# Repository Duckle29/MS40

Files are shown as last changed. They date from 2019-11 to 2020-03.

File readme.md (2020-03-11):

View this project on [CADLAB.io](https://cadlab.io/project/2268). 

# MS40

[Interactive BOM](https://duckle29.github.io/MS40/ibom.html)

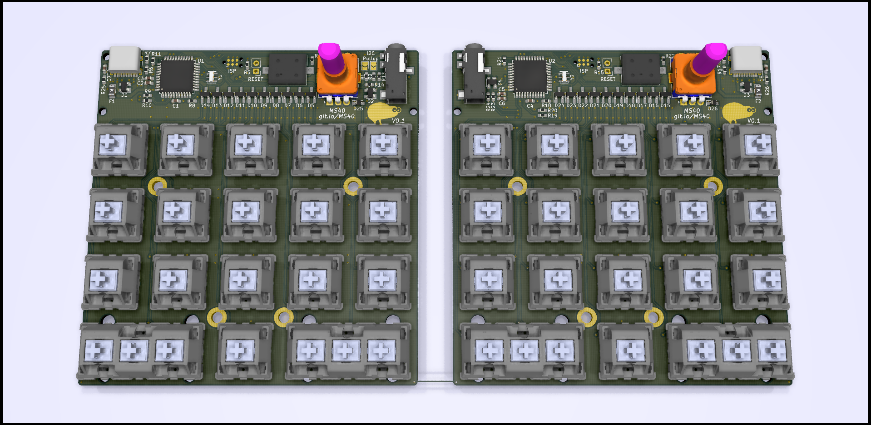
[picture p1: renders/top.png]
top render

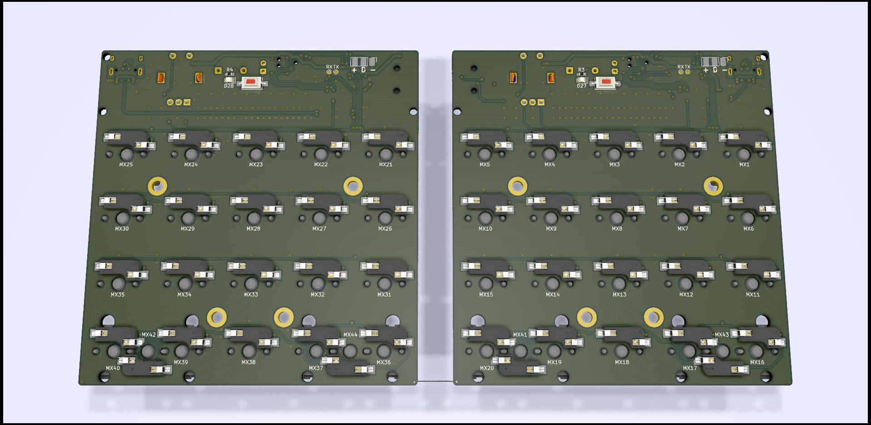
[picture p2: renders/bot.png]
bottom render


The project uses Ai03s keyswitch library.
Many thanks to Ai03 for releasing an awesome keyswitch library with an entirely open license.

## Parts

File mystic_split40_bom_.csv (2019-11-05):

Id | Designator | Package | Quantity | Designation | Supplier and ref
1 | G***,G*** | kiwi10mm | 2 | LOGO
2 | MX44,MX43,MX42,MX41 | MXOnly-2U-Hotswap | 4 | MX-NoLED
3 | J5,J2 | TestPoint_Pad_D1.0mm | 2 | TX
4 | J3,J1 | TestPoint_Pad_D1.0mm | 2 | RX
5 | F2,F1 | Fuse_1206_3216Metric_Pad1.42x1.75mm_HandSolder | 2 | ?mA fuse
6 | D3,D4,D2,D1 | SOT-143 | 4 | PRTR5V0U2X
7 | J35,J17 | PinHeader_1x03_P2.54mm_Vertical | 2 | WS2812
8 | R15,R17,R16,R21,R5,R11,R7,R6,R2,R1 | R_0603_1608Metric_Pad1.05x0.95mm_HandSolder | 10 | 5k1
9 | SW2,SW1 | RotaryEncoder_Alps_EC11E-Switch_Vertical_H20mm | 2 | EC11E
10 | SW4,SW3 | SW_SPST_CK_RS282G05A3 | 2 | Reset
11 | D26,D25 | D_SOD-323_HandSoldering | 2 | BAV70
12 | MX22,MX36,MX23,MX25,MX37,MX31,MX24,MX27,MX28,MX29,MX30,MX33,MX34,MX32,MX38,MX40,MX26,MX39,MX35,MX21,MX5,MX3,MX16,MX2,MX20,MX19,MX18,MX17,MX15,MX14,MX13,MX12,MX11,MX10,MX9,MX8,MX7,MX6,MX4,MX1 | MXOnly-1U-Hotswap | 40 | MX-NoLED
13 | U2,U1 | TQFP-44_10x10mm_P0.8mm | 2 | ATmega32U4-AU
14 | J22 | TestPoint_Pad_D1.0mm | 1 | AREF
15 | J36,J18 | SJ-43514-SMT | 2 | SJ-43514-SMT
16 | BZ3,BZ1 | Buzzer_12x9.5RM7.6 | 2 | Buzzer_magnetic
17 | R4,R24,R23,R22,R18,R3,R14,R13,R12,R8 | R_0603_1608Metric_Pad1.05x0.95mm_HandSolder | 10 | 220R
18 | D28,D27 | LED_0805_2012Metric_Pad1.15x1.40mm_HandSolder | 2 | Red LED
19 | REF**,REF**,REF**,REF**,REF**,REF** | MountingHole_2.2mm_M2_DIN965 | 6 | MountingHole_2.2mm_M2_DIN965
20 | REF**,REF**,REF**,REF**,REF**,REF**,REF**,REF** | MountingHole_3.2mm_M3_DIN965_Pad | 8 | MountingHole_3.2mm_M3_DIN965_Pad
21 | C5,C2 | C_0603_1608Metric_Pad1.05x0.95mm_HandSolder | 2 | 100nF
22 | C4,C6,C3,C1 | C_0603_1608Metric_Pad1.05x0.95mm_HandSolder | 4 | 1uF
23 | D15,D23,D21,D19,D22,D18,D20,D17,D24,D16,D6,D8,D10,D12,D14,D5,D7,D9,D11,D13 | SOT-23_Handsoldering | 20 | BAV70
24 | BZ4,BZ2 | Buzzer_Mallory_AST1109MLTRQ | 2 | Buzzer_piezo
25 | Y2,Y1 | Resonator_SMD_muRata_CSTxExxV-3Pin_3.0x1.1mm_HandSoldering | 2 | CSTNE16M0VH3L000R0
26 | R20,R19,R10,R9 | R_0603_1608Metric_Pad1.05x0.95mm_HandSolder | 4 | 22R
27 | J25,J7 | USB_C_Receptacle_HRO_TYPE-C-31-M-12 | 2 | TYPE-C-31-M-12
28 | J33,J15 | PinHeader_1x02_P2.54mm_Vertical | 2 | RESET
29 | J34,J16 | Tag-Connect_TC2030-IDC-NL_2x03_P1.27mm_Vertical | 2 | ISP
30 | JP2,JP1 | SolderJumper-2_P1.3mm_Open_TrianglePad1.0x1.5mm | 2 | I2C pullup

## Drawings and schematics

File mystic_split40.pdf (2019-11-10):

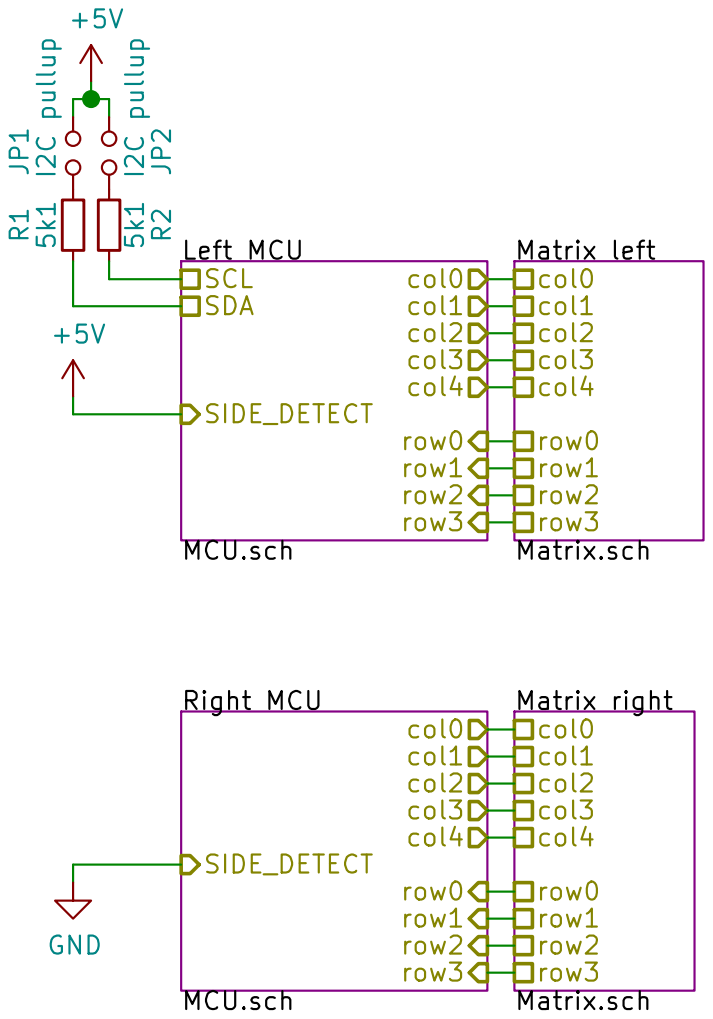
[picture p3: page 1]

row3 Right MCU MCU.sch

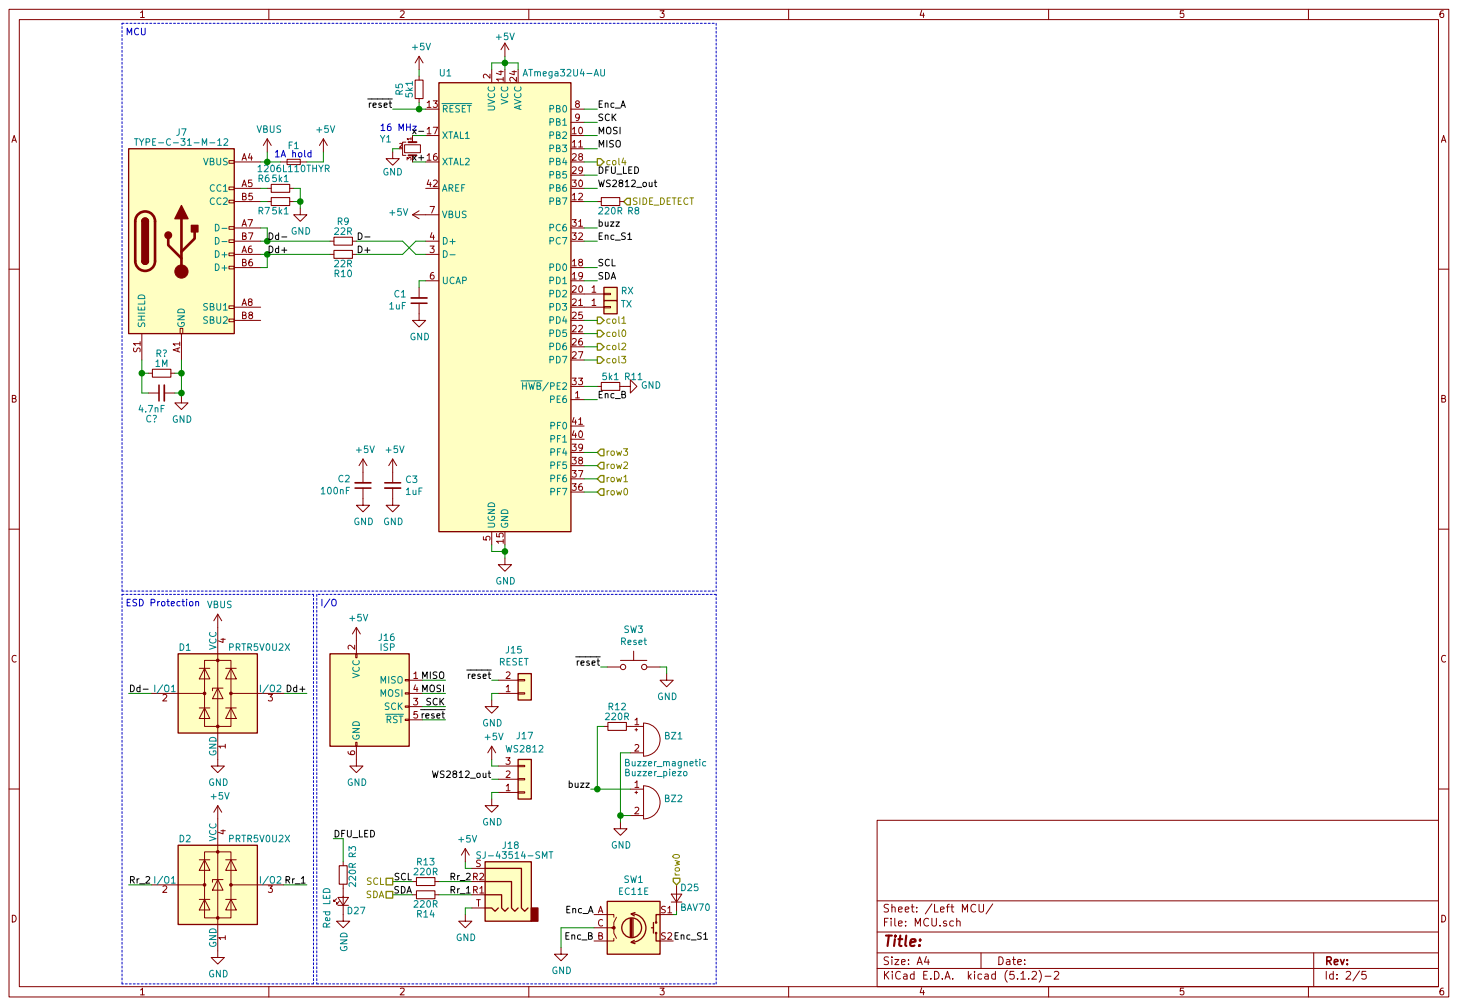
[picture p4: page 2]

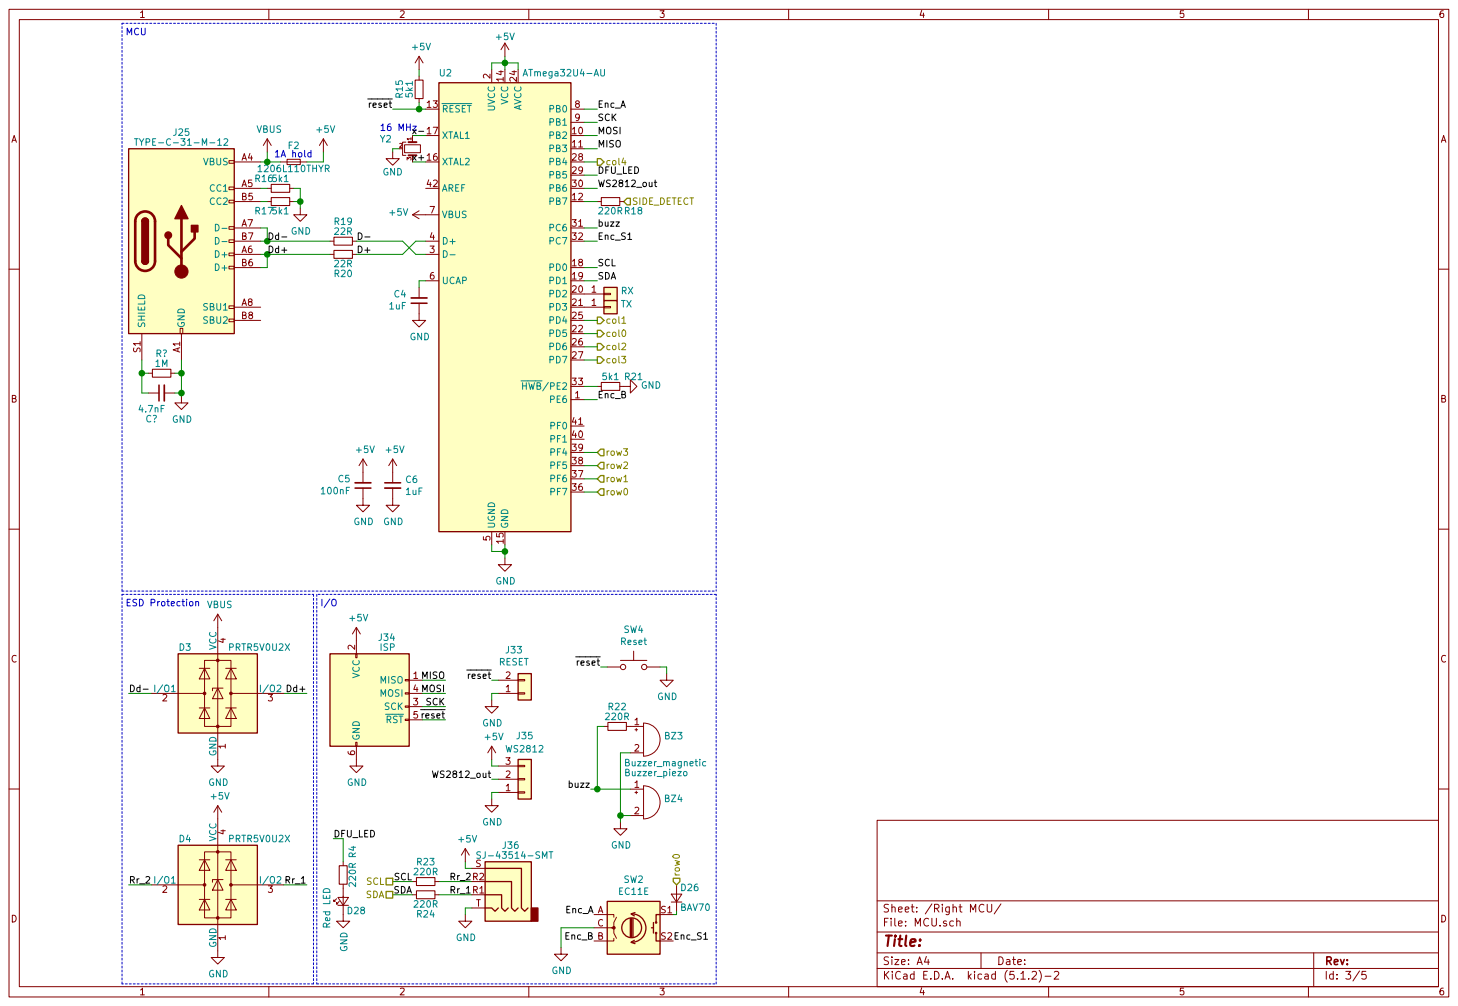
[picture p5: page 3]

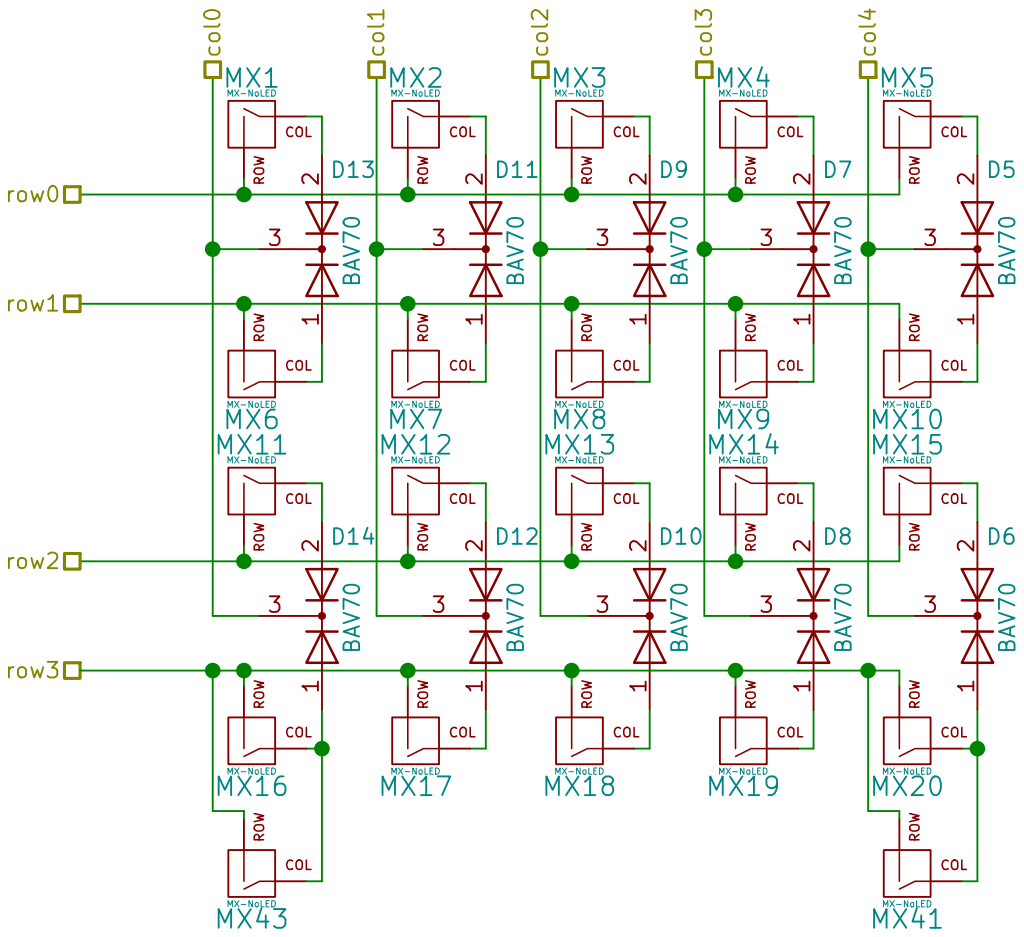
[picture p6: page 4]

Id: 4/5 Title: File: Matrix.sch Sheet: /Matrix left/

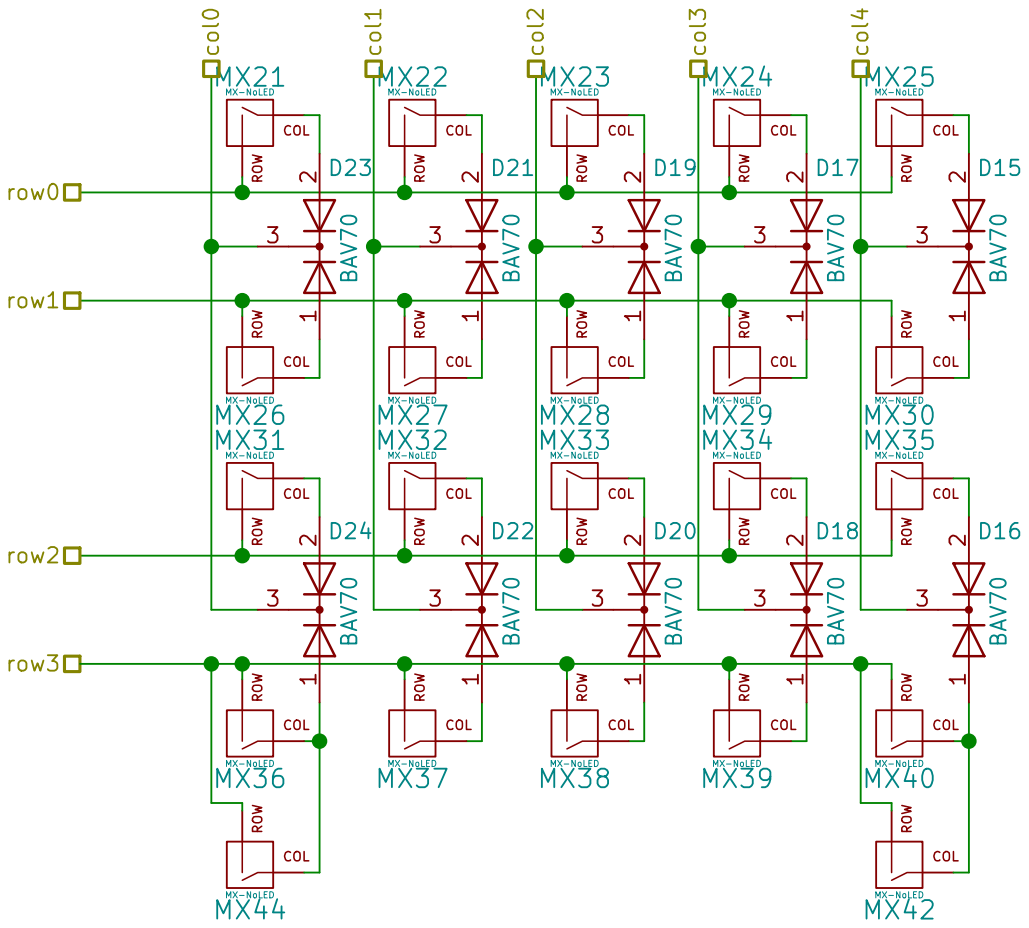
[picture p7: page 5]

Id: 5/5 Title: File: Matrix.sch Sheet: /Matrix right/

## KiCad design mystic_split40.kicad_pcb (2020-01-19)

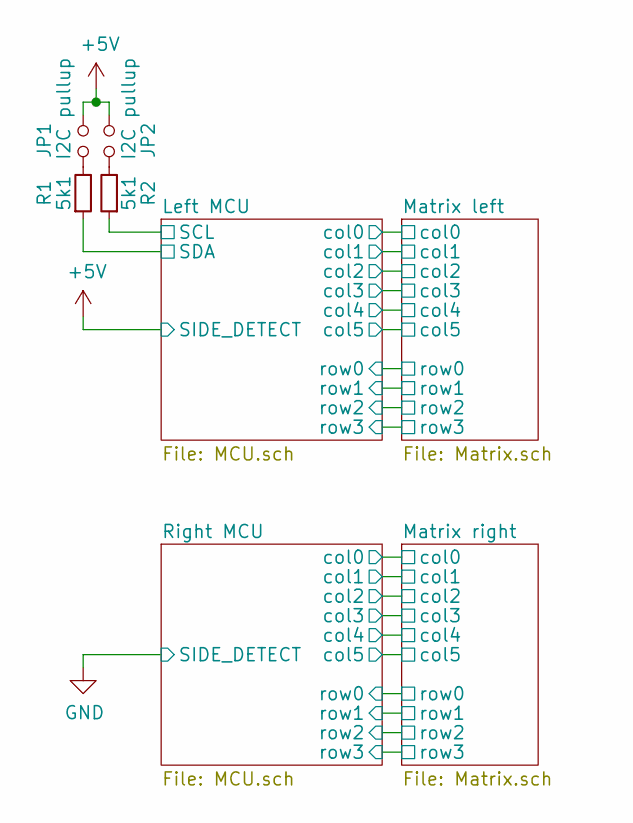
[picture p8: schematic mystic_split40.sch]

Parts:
JP1, JP2: I2C pullup; SolderJumper-2_P1.3mm_Open_TrianglePad1.0x1.5mm
R1, R2: 5k1; R_0603_1608Metric_Pad1.05x0.95mm_HandSolder

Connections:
+5V: JP1.1, JP2.1; also elsewhere on the board
/Left MCU/SCL: R2.1; also elsewhere on the board
/Left MCU/SDA: R1.1; also elsewhere on the board
unnamed: JP1.2, R1.2
unnamed: JP2.2, R2.2

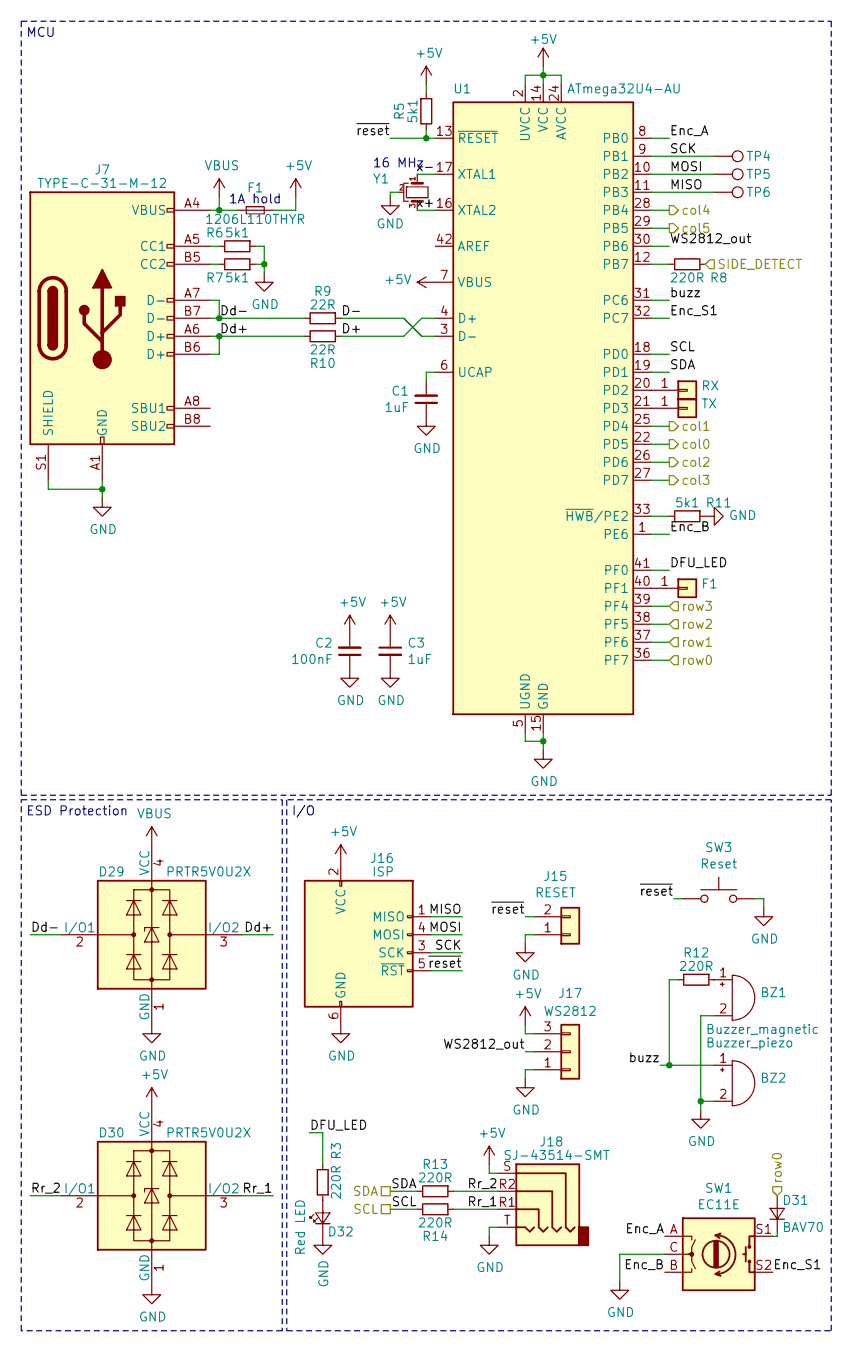
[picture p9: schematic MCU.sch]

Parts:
BZ1: Buzzer_magnetic; Buzzer_12x9.5RM7.6
BZ2: Buzzer_piezo; Buzzer_Mallory_AST1109MLTRQ
C1, C3: 1uF; C_0603_1608Metric_Pad1.05x0.95mm_HandSolder
C2: 100nF; C_0603_1608Metric_Pad1.05x0.95mm_HandSolder
D29, D30: PRTR5V0U2X; SOT-143
D31: BAV70; D_SOD-323_HandSoldering
D32: Red LED; LED_0805_2012Metric_Pad1.15x1.40mm_HandSolder
F1: 1206L110THYR; Fuse_1206_3216Metric_Pad1.42x1.75mm_HandSolder
J1: RX; TestPoint_Pad_D1.0mm
J2: TX; TestPoint_Pad_D1.0mm
J6: F1; TestPoint_Pad_D1.0mm
J7: TYPE-C-31-M-12; USB_C_Receptacle_HRO_TYPE-C-31-M-12
J15: RESET; PinHeader_1x02_P2.54mm_Vertical
J16: ISP; Tag-Connect_TC2030-IDC-NL_2x03_P1.27mm_Vertical
J17: WS2812; PinHeader_1x03_P2.54mm_Vertical
J18: SJ-43514-SMT
R3, R8, R12, R13, R14: 220R; R_0603_1608Metric_Pad1.05x0.95mm_HandSolder
R5, R6, R7, R11: 5k1; R_0603_1608Metric_Pad1.05x0.95mm_HandSolder
R9, R10: 22R; R_0603_1608Metric_Pad1.05x0.95mm_HandSolder
SW1: EC11E; RotaryEncoder_Alps_EC11E-Switch_Vertical_H20mm
SW3: Reset; SW_SPST_CK_RS282G05A3
TP4: SCK; TestPoint_Pad_D1.0mm
TP5: MOSI; TestPoint_Pad_D1.0mm
TP6: MISO; TestPoint_Pad_D1.0mm
U1: ATmega32U4-AU; TQFP-44_10x10mm_P0.8mm
Y1: CSTNE16M0VH3L000R0; Resonator_SMD_muRata_CSTxExxV-3Pin_3.0x1.1mm_HandSoldering

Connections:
+5V: C2.2, C3.1, D30.4 (VCC), F1.2, J16.2 (VCC), J17.3, J18.S, R5.1, R8.2, U1.2 (UVCC), U1.7 (VBUS), U1.14 (VCC), U1.24 (AVCC), U1.34 (VCC), U1.44 (AVCC); also elsewhere on the board
/Left MCU/D+: R10.1, U1.4 (D+)
/Left MCU/D-: R9.1, U1.3 (D-)
/Left MCU/DFU_LED: R3.2, U1.41 (PF0)
/Left MCU/Dd+: D29.3 (I/O2), J7.A6 (D+), J7.B6 (D+), R10.2
/Left MCU/Dd-: D29.2 (I/O1), J7.A7 (D-), J7.B7 (D-), R9.2
/Left MCU/Enc_A: SW1.A, U1.8 (PB0)
/Left MCU/Enc_B: SW1.B, U1.1 (PE6)
/Left MCU/Enc_S1: SW1.S2, U1.32 (PC7)
/Left MCU/MISO: J16.1 (MISO), TP6.1, U1.11 (PB3)
/Left MCU/MOSI: J16.4 (MOSI), TP5.1, U1.10 (PB2)
/Left MCU/Rr_1: D30.3 (I/O2), J18.R1, R14.1
/Left MCU/Rr_2: D30.2 (I/O1), J18.R2, R13.1
/Left MCU/SCK: J16.3 (SCK), TP4.1, U1.9 (PB1)
/Left MCU/SCL: R14.2, U1.18 (PD0); also elsewhere on the board
/Left MCU/SDA: R13.2, U1.19 (PD1); also elsewhere on the board
/Left MCU/WS2812_out: J17.2, U1.30 (PB6)
/Left MCU/buzz: BZ2.1 (-), R12.2, U1.31 (PC6)
/Left MCU/col0: U1.22 (PD5); also elsewhere on the board
/Left MCU/col1: U1.25 (PD4); also elsewhere on the board
/Left MCU/col2: U1.26 (PD6); also elsewhere on the board
/Left MCU/col3: U1.27 (PD7); also elsewhere on the board
/Left MCU/col4: U1.28 (PB4); also elsewhere on the board
/Left MCU/col5: U1.29 (PB5); also elsewhere on the board
/Left MCU/row0: D31.2 (A), U1.36 (PF7); also elsewhere on the board
/Left MCU/row1: U1.37 (PF6); also elsewhere on the board
/Left MCU/row2: U1.38 (PF5); also elsewhere on the board
/Left MCU/row3: U1.39 (PF4); also elsewhere on the board
/Left MCU/x+: U1.16 (XTAL2), Y1.3
/Left MCU/x-: U1.17 (XTAL1), Y1.1
/Left MCU/~reset: J15.2, J16.5 (~RST), R5.2, SW3.1, U1.13 (~RESET)
GND: BZ1.2 (+), BZ2.2 (+), C1.1, C2.1, C3.2, D29.1 (GND), D30.1 (GND), D32.1 (K), J7.A1 (GND), J7.A12 (GND), J7.B1 (GND), J7.B12 (GND), J7.S1 (SHIELD), J15.1, J16.6 (GND), J17.1, J18.T, R6.1, R7.1, R11.1, SW1.C, SW1.MP, SW3.2, U1.5 (UGND), U1.15 (GND), U1.23 (GND), U1.35 (GND), U1.43 (GND), Y1.2; also elsewhere on the board
unnamed: BZ1.1 (-), R12.1
unnamed: C1.2, U1.6 (UCAP)
unnamed: D31.1 (K), SW1.S1
unnamed: D32.2 (A), R3.1
unnamed: J1.1, U1.20 (PD2)
unnamed: J2.1, U1.21 (PD3)
unnamed: J6.1, U1.40 (PF1)
unnamed: J7.A5 (CC1), R6.2
unnamed: J7.B5 (CC2), R7.2
unnamed: R8.1, U1.12 (PB7)
unnamed: R11.2, U1.33 (~HWB~/PE2)
VBUS: D29.4 (VCC), F1.1, J7.A4 (VBUS), J7.A9 (VBUS), J7.B4 (VBUS), J7.B9 (VBUS); also elsewhere on the board

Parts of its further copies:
BZ3: Buzzer_magnetic; Buzzer_12x9.5RM7.6
BZ4: Buzzer_piezo; Buzzer_Mallory_AST1109MLTRQ
C4, C6: 1uF; C_0603_1608Metric_Pad1.05x0.95mm_HandSolder
C5: 100nF; C_0603_1608Metric_Pad1.05x0.95mm_HandSolder
D1, D2: PRTR5V0U2X; SOT-143
D27: BAV70; D_SOD-323_HandSoldering
D28: Red LED; LED_0805_2012Metric_Pad1.15x1.40mm_HandSolder
F2: 1206L110THYR; Fuse_1206_3216Metric_Pad1.42x1.75mm_HandSolder
J3: RX; TestPoint_Pad_D1.0mm
J5: TX; TestPoint_Pad_D1.0mm
J9: F1; TestPoint_Pad_D1.0mm
J25: TYPE-C-31-M-12; USB_C_Receptacle_HRO_TYPE-C-31-M-12
J33: RESET; PinHeader_1x02_P2.54mm_Vertical
J34: ISP; Tag-Connect_TC2030-IDC-NL_2x03_P1.27mm_Vertical
J35: WS2812; PinHeader_1x03_P2.54mm_Vertical
J36: SJ-43514-SMT
R4, R18, R22, R23, R24: 220R; R_0603_1608Metric_Pad1.05x0.95mm_HandSolder
R15, R16, R17, R21: 5k1; R_0603_1608Metric_Pad1.05x0.95mm_HandSolder
R19, R20: 22R; R_0603_1608Metric_Pad1.05x0.95mm_HandSolder
SW2: EC11E; RotaryEncoder_Alps_EC11E-Switch_Vertical_H20mm
SW4: Reset; SW_SPST_CK_RS282G05A3
TP1: SCK; TestPoint_Pad_D1.0mm
TP2: MOSI; TestPoint_Pad_D1.0mm
TP3: MISO; TestPoint_Pad_D1.0mm
U2: ATmega32U4-AU; TQFP-44_10x10mm_P0.8mm
Y2: CSTNE16M0VH3L000R0; Resonator_SMD_muRata_CSTxExxV-3Pin_3.0x1.1mm_HandSoldering

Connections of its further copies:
+5V: C5.2, C6.1, D2.4 (VCC), F2.2, J34.2 (VCC), J35.3, J36.S, R15.1, U2.2 (UVCC), U2.7 (VBUS), U2.14 (VCC), U2.24 (AVCC), U2.34 (VCC), U2.44 (AVCC); also elsewhere on the board
/Matrix right/col0: U2.22 (PD5); also elsewhere on the board
/Matrix right/col1: U2.25 (PD4); also elsewhere on the board
/Matrix right/col2: U2.26 (PD6); also elsewhere on the board
/Matrix right/col3: U2.27 (PD7); also elsewhere on the board
/Matrix right/col4: U2.28 (PB4); also elsewhere on the board
/Matrix right/col5: U2.29 (PB5); also elsewhere on the board
/Matrix right/row0: D27.2 (A), U2.36 (PF7); also elsewhere on the board
/Matrix right/row1: U2.37 (PF6); also elsewhere on the board
/Matrix right/row2: U2.38 (PF5); also elsewhere on the board
/Matrix right/row3: U2.39 (PF4); also elsewhere on the board
/Right MCU/D+: R20.1, U2.4 (D+)
/Right MCU/D-: R19.1, U2.3 (D-)
/Right MCU/DFU_LED: R4.2, U2.41 (PF0)
/Right MCU/Dd+: D1.3 (I/O2), J25.A6 (D+), J25.B6 (D+), R20.2
/Right MCU/Dd-: D1.2 (I/O1), J25.A7 (D-), J25.B7 (D-), R19.2
/Right MCU/Enc_A: SW2.A, U2.8 (PB0)
/Right MCU/Enc_B: SW2.B, U2.1 (PE6)
/Right MCU/Enc_S1: SW2.S2, U2.32 (PC7)
/Right MCU/MISO: J34.1 (MISO), TP3.1, U2.11 (PB3)
/Right MCU/MOSI: J34.4 (MOSI), TP2.1, U2.10 (PB2)
/Right MCU/Rr_1: D2.3 (I/O2), J36.R1, R24.1
/Right MCU/Rr_2: D2.2 (I/O1), J36.R2, R23.1
/Right MCU/SCK: J34.3 (SCK), TP1.1, U2.9 (PB1)
/Right MCU/SCL: R24.2, U2.18 (PD0)
/Right MCU/SDA: R23.2, U2.19 (PD1)
/Right MCU/WS2812_out: J35.2, U2.30 (PB6)
/Right MCU/buzz: BZ4.1 (-), R22.2, U2.31 (PC6)
/Right MCU/x+: U2.16 (XTAL2), Y2.3
/Right MCU/x-: U2.17 (XTAL1), Y2.1
/Right MCU/~reset: J33.2, J34.5 (~RST), R15.2, SW4.1, U2.13 (~RESET)
GND: BZ3.2 (+), BZ4.2 (+), C4.1, C5.1, C6.2, D1.1 (GND), D2.1 (GND), D28.1 (K), J25.A1 (GND), J25.A12 (GND), J25.B1 (GND), J25.B12 (GND), J25.S1 (SHIELD), J33.1, J34.6 (GND), J35.1, J36.T, R16.1, R17.1, R18.2, R21.1, SW2.C, SW4.2, U2.5 (UGND), U2.15 (GND), U2.23 (GND), U2.35 (GND), U2.43 (GND), Y2.2; also elsewhere on the board
unnamed: BZ3.1 (-), R22.1
unnamed: C4.2, U2.6 (UCAP)
unnamed: D27.1 (K), SW2.S1
unnamed: D28.2 (A), R4.1
unnamed: J3.1, U2.20 (PD2)
unnamed: J5.1, U2.21 (PD3)
unnamed: J9.1, U2.40 (PF1)
unnamed: J25.A5 (CC1), R16.2
unnamed: J25.B5 (CC2), R17.2
unnamed: R18.1, U2.12 (PB7)
unnamed: R21.2, U2.33 (~HWB~/PE2)
VBUS: D1.4 (VCC), F2.1, J25.A4 (VBUS), J25.A9 (VBUS), J25.B4 (VBUS), J25.B9 (VBUS); also elsewhere on the board

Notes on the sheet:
ESD Protection
MCU
16 MHz
I/O
1A hold

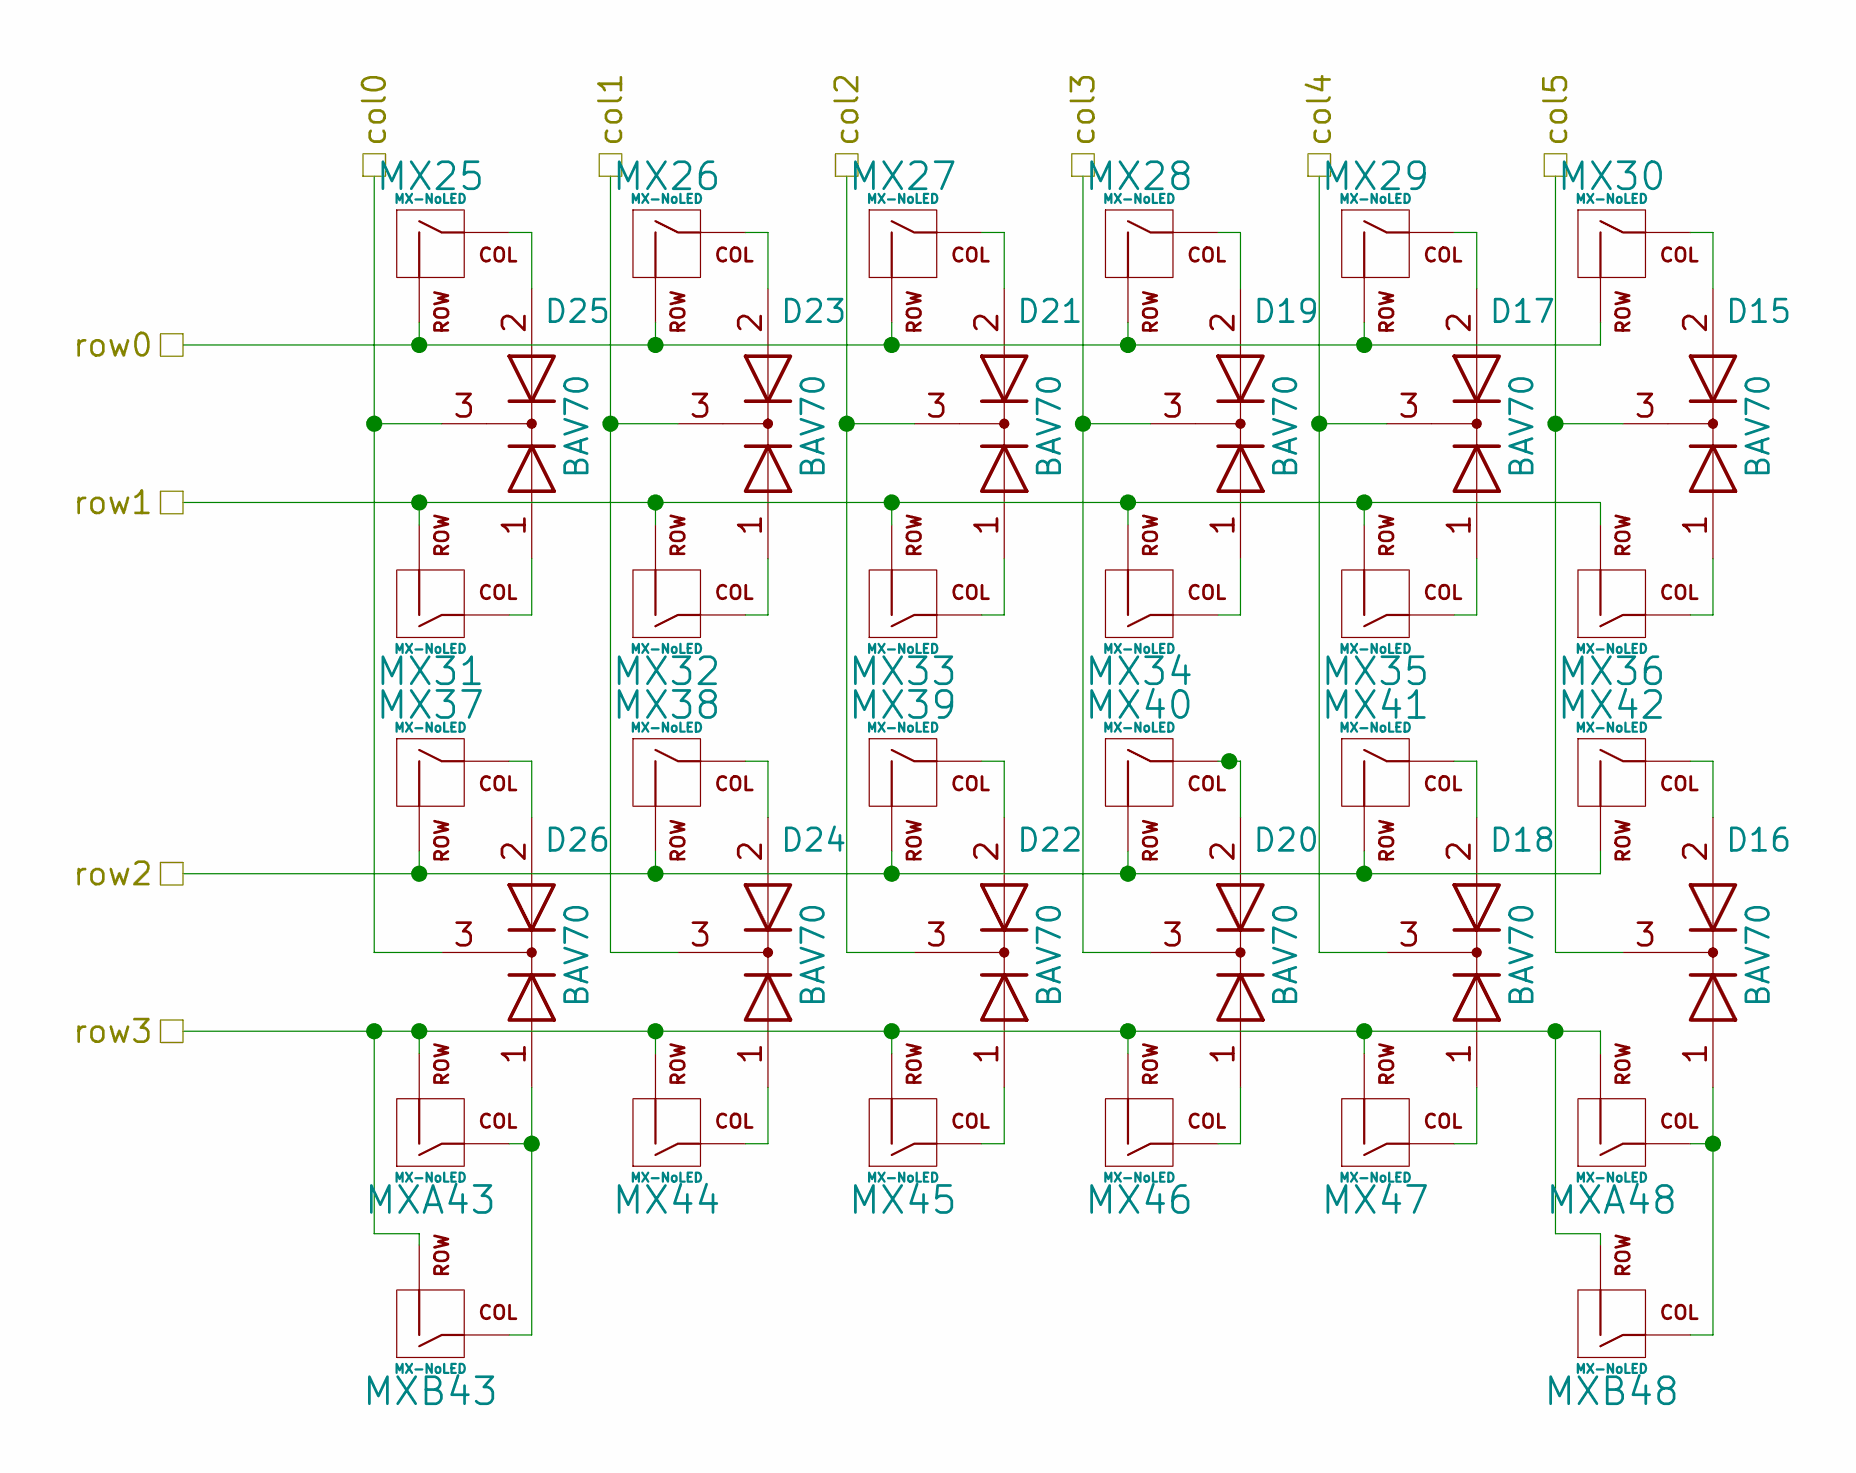
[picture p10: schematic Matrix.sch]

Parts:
D3, D4, D5, D6, D7, D8, D9, D10, D11, D12, D13, D14: BAV70; SOT-23_Handsoldering
MX1, MX2, MX3, MX4, MX5, MX6, MX7, MX8, MX9, MX10, MX11, MX12, MX13, MX14, MX15, MX16, MX17, MX18, MX20, MX21, MX22, MX23: MX-NoLED; MXOnly-1U-Hotswap
MXA19, MXA24: MX-NoLED; MXOnly-1U-Hotswap
MXB19, MXB24: MX-NoLED; MXOnly-2U-Hotswap

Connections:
/Left MCU/col0: D13.3 (K), D14.3 (K); also elsewhere on the board
/Left MCU/col1: D11.3 (K), D12.3 (K); also elsewhere on the board
/Left MCU/col2: D9.3 (K), D10.3 (K); also elsewhere on the board
/Left MCU/col3: D7.3 (K), D8.3 (K); also elsewhere on the board
/Left MCU/col4: D5.3 (K), D6.3 (K); also elsewhere on the board
/Left MCU/col5: D3.3 (K), D4.3 (K); also elsewhere on the board
/Left MCU/row0: MX1.2 (ROW), MX2.2 (ROW), MX3.2 (ROW), MX4.2 (ROW), MX5.2 (ROW), MX6.2 (ROW); also elsewhere on the board
/Left MCU/row1: MX7.2 (ROW), MX8.2 (ROW), MX9.2 (ROW), MX10.2 (ROW), MX11.2 (ROW), MX12.2 (ROW); also elsewhere on the board
/Left MCU/row2: MX13.2 (ROW), MX14.2 (ROW), MX15.2 (ROW), MX16.2 (ROW), MX17.2 (ROW), MX18.2 (ROW); also elsewhere on the board
/Left MCU/row3: MX20.2 (ROW), MX21.2 (ROW), MX22.2 (ROW), MX23.2 (ROW), MXA19.2 (ROW), MXA24.2 (ROW), MXB19.2 (ROW), MXB24.2 (ROW); also elsewhere on the board
unnamed: D3.1 (A), MX12.1 (COL)
unnamed: D3.2 (A), MX6.1 (COL)
unnamed: D4.1 (A), MXA24.1 (COL), MXB24.1 (COL)
unnamed: D4.2 (A), MX18.1 (COL)
unnamed: D5.1 (A), MX11.1 (COL)
unnamed: D5.2 (A), MX5.1 (COL)
unnamed: D6.1 (A), MX23.1 (COL)
unnamed: D6.2 (A), MX17.1 (COL)
unnamed: D7.1 (A), MX10.1 (COL)
unnamed: D7.2 (A), MX4.1 (COL)
unnamed: D8.1 (A), MX22.1 (COL)
unnamed: D8.2 (A), MX16.1 (COL)
unnamed: D9.1 (A), MX9.1 (COL)
unnamed: D9.2 (A), MX3.1 (COL)
unnamed: D10.1 (A), MX21.1 (COL)
unnamed: D10.2 (A), MX15.1 (COL)
unnamed: D11.1 (A), MX8.1 (COL)
unnamed: D11.2 (A), MX2.1 (COL)
unnamed: D12.1 (A), MX20.1 (COL)
unnamed: D12.2 (A), MX14.1 (COL)
unnamed: D13.1 (A), MX7.1 (COL)
unnamed: D13.2 (A), MX1.1 (COL)
unnamed: D14.1 (A), MXA19.1 (COL), MXB19.1 (COL)
unnamed: D14.2 (A), MX13.1 (COL)

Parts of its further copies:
D15, D16, D17, D18, D19, D20, D21, D22, D23, D24, D25, D26: BAV70; SOT-23_Handsoldering
MX25, MX26, MX27, MX28, MX29, MX30, MX31, MX32, MX33, MX34, MX35, MX36, MX37, MX38, MX39, MX40, MX41, MX42, MX44, MX45, MX46, MX47: MX-NoLED; MXOnly-1U-Hotswap
MXA43, MXA48: MX-NoLED; MXOnly-1U-Hotswap
MXB43, MXB48: MX-NoLED; MXOnly-2U-Hotswap

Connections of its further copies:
/Matrix right/col0: D25.3 (K), D26.3 (K); also elsewhere on the board
/Matrix right/col1: D23.3 (K), D24.3 (K); also elsewhere on the board
/Matrix right/col2: D21.3 (K), D22.3 (K); also elsewhere on the board
/Matrix right/col3: D19.3 (K), D20.3 (K); also elsewhere on the board
/Matrix right/col4: D17.3 (K), D18.3 (K); also elsewhere on the board
/Matrix right/col5: D15.3 (K), D16.3 (K); also elsewhere on the board
/Matrix right/row0: MX25.2 (ROW), MX26.2 (ROW), MX27.2 (ROW), MX28.2 (ROW), MX29.2 (ROW), MX30.2 (ROW); also elsewhere on the board
/Matrix right/row1: MX31.2 (ROW), MX32.2 (ROW), MX33.2 (ROW), MX34.2 (ROW), MX35.2 (ROW), MX36.2 (ROW); also elsewhere on the board
/Matrix right/row2: MX37.2 (ROW), MX38.2 (ROW), MX39.2 (ROW), MX40.2 (ROW), MX41.2 (ROW), MX42.2 (ROW); also elsewhere on the board
/Matrix right/row3: MX44.2 (ROW), MX45.2 (ROW), MX46.2 (ROW), MX47.2 (ROW), MXA43.2 (ROW), MXA48.2 (ROW), MXB43.2 (ROW), MXB48.2 (ROW); also elsewhere on the board
unnamed: D15.1 (A), MX36.1 (COL)
unnamed: D15.2 (A), MX30.1 (COL)
unnamed: D16.1 (A), MXA48.1 (COL), MXB48.1 (COL)
unnamed: D16.2 (A), MX42.1 (COL)
unnamed: D17.1 (A), MX35.1 (COL)
unnamed: D17.2 (A), MX29.1 (COL)
unnamed: D18.1 (A), MX47.1 (COL)
unnamed: D18.2 (A), MX41.1 (COL)
unnamed: D19.1 (A), MX34.1 (COL)
unnamed: D19.2 (A), MX28.1 (COL)
unnamed: D20.1 (A), MX46.1 (COL)
unnamed: D20.2 (A), MX40.1 (COL)
unnamed: D21.1 (A), MX33.1 (COL)
unnamed: D21.2 (A), MX27.1 (COL)
unnamed: D22.1 (A), MX45.1 (COL)
unnamed: D22.2 (A), MX39.1 (COL)
unnamed: D23.1 (A), MX32.1 (COL)
unnamed: D23.2 (A), MX26.1 (COL)
unnamed: D24.1 (A), MX44.1 (COL)
unnamed: D24.2 (A), MX38.1 (COL)
unnamed: D25.1 (A), MX31.1 (COL)
unnamed: D25.2 (A), MX25.1 (COL)
unnamed: D26.1 (A), MXA43.1 (COL), MXB43.1 (COL)
unnamed: D26.2 (A), MX37.1 (COL)

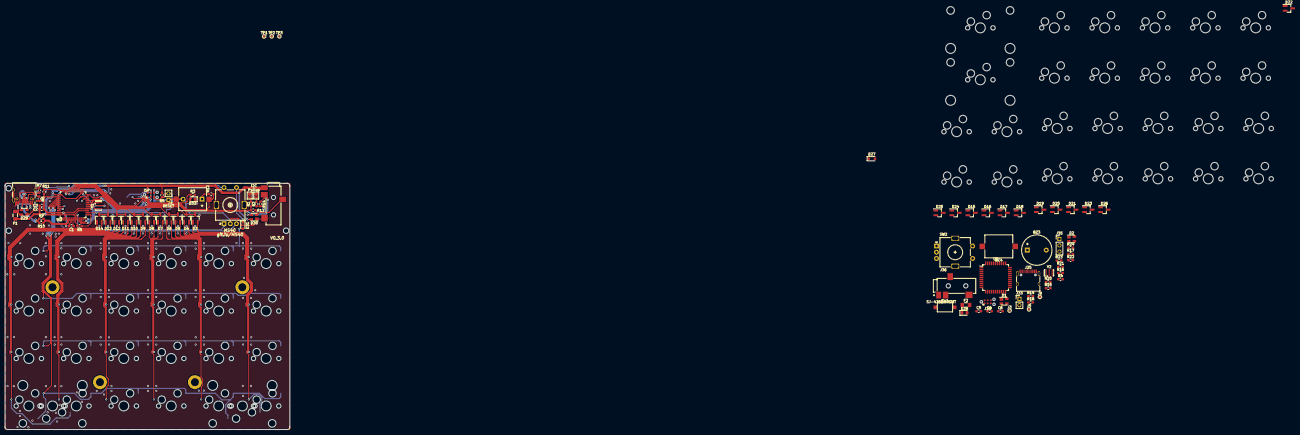
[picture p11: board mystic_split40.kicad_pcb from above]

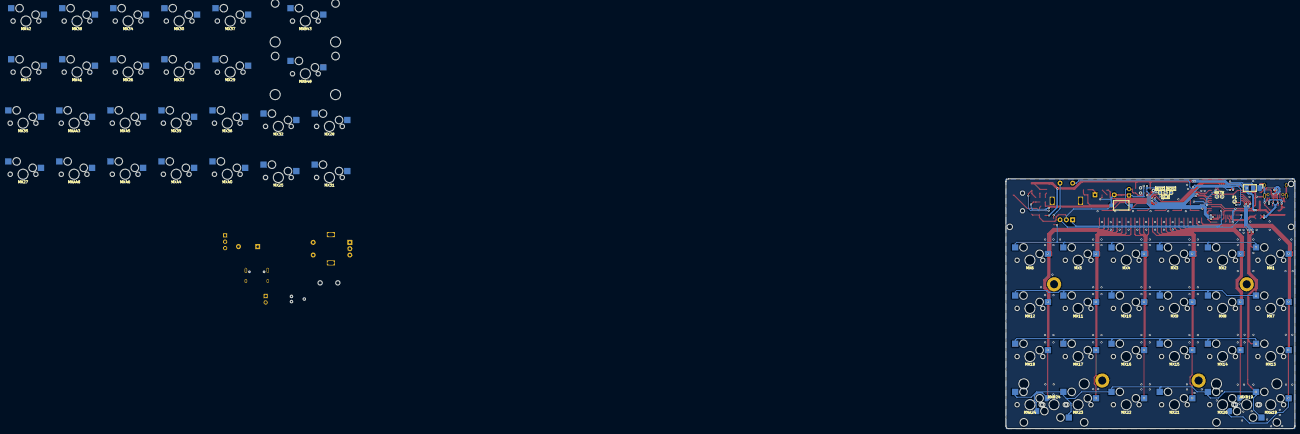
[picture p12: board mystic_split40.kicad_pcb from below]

Board: 2 copper layers, 114.3 x 98.8 mm, 152 parts (8 on the bottom side), 135 nets.

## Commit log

2019-11-04 Updated symbol library names
    [MCU.sch, MMboard1.sch, Matrix.sch]
2019-11-04 Added CUI connector lib
    [MCU.sch, MMboard1.kicad_pcb]
2019-11-04 Renamed board
    [mystic_split40.kicad_pcb, mystic_split40.sch]
2019-11-04 Added 3D models, prettied up silk
    [MCU.sch, Matrix.sch, mystic_split40.kicad_pcb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]
2019-11-05 Copied left half layout to right components
    [MCU.sch, mystic_split40.kicad_pcb, mystic_split40.sch]
2019-11-05 Finished right-side, added BOM
    [MCU.sch, Matrix.sch, mystic_split40.kicad_pcb]
2019-11-05 Added CSV BOM
    [mystic_split40.csv]
2019-11-06 Started work on hosting ibom on gh-pages
    [mystic_split40.kicad_pcb, mystic_split40_bom_.csv]
2019-11-06 Fixed up silkscreen
    [MCU.sch, mystic_split40.kicad_pcb]
2019-11-06 Moved WS2812 pads and added pinout
    [mystic_split40.kicad_pcb]
2019-11-06 Added kicad renders
    [mystic_split40.kicad_pcb]
2019-11-06 Further silk cleanup
    [mystic_split40.kicad_pcb]
2019-11-08 Added qmk hardware lib
    [mystic_split40.kicad_pcb]
2019-11-10 Connected USB shield via RC filter, updated renders
    [MCU.sch, mystic_split40.kicad_pcb]
2019-11-10 Saved pcbnew
    [mystic_split40.kicad_pcb]
2019-11-11 Swapped SDA and SCL pins on TRRS jack
    [MCU.sch, mystic_split40.kicad_pcb]
2019-11-11 Changed right USB peg holes to solid pour connection
    [mystic_split40.kicad_pcb]
2019-11-11 Improved ground routing from ISP header
    [mystic_split40.kicad_pcb]
2019-11-12 regenerated gerbers
    [MCU.sch, mystic_split40.kicad_pcb]
2020-01-19 Started work on adding extra col
    [MCU.sch, Matrix.sch, mystic_split40.kicad_pcb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]
2020-01-19 Changed version silk
    [mystic_split40.kicad_pcb]
